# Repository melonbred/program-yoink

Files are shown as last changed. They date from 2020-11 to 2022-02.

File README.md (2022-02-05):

# Program Yoink!

This PCB is for a 12u main cluster with exploded arrow cluster, macro column and rotary encoder support. Progam Yoink! was a collaborative project with Steve Laroo, P3D Store, and Keybage. 

- Big bar and split bar support
- MX switch support only
- USB Type-C.
- ESD Protection
- RGB lightbar

## Layout
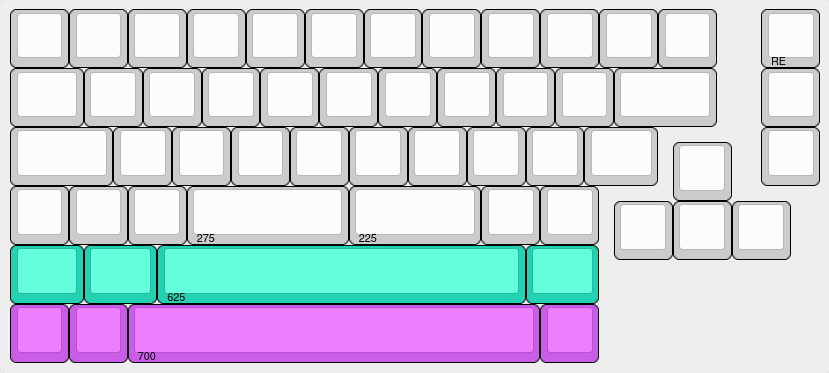
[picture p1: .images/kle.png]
 

[KLE](http://www.keyboard-layout-editor.com/#/gists/345cd9f384dae3f91f5151f02f8af4df)

 ## PCB
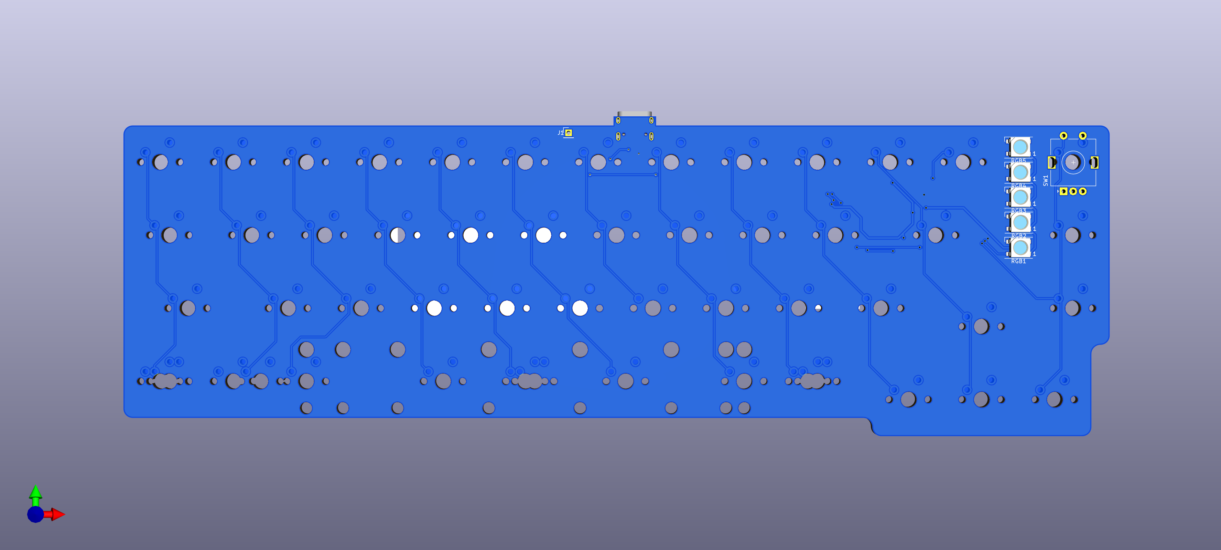
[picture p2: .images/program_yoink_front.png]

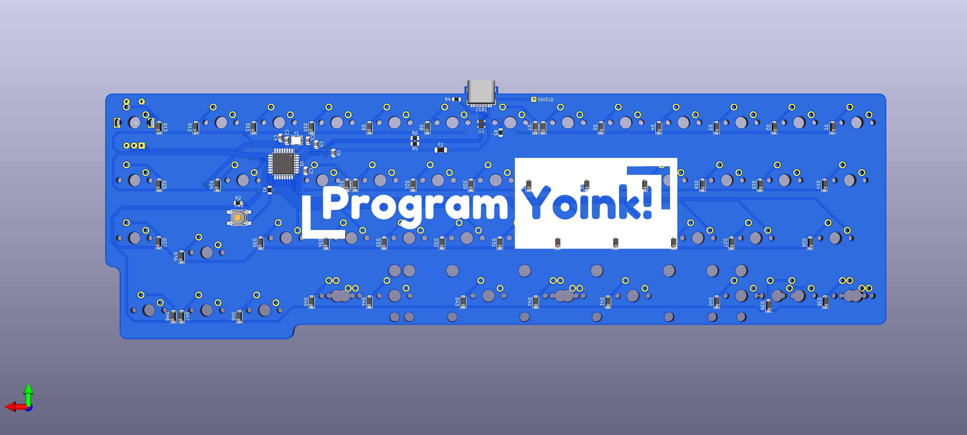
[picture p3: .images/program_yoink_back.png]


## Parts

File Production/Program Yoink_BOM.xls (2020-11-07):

Item No. | Designator | Quantity | Value | Footprint | Manufacturer | Part No. | Description
1 | R2,R1 | 2 | 10k | 0805 | Panasonic Electronic Components | ERA-6AEB103V | RES 10K OHM 0.1% 1/8W 0805
2 | USB1 | 1 | HRO-TYPE-C-31-M-12 | HRO-TYPE-C-31-M-12-HandSoldering | Korean Hroparts Elec | TYPE-C-31-M-12 | USB - Type C Female 16 8.94*7.3mm USB Connectors RoHS
3 | U2 | 1 | PRTR5V0U2X | SOT-143 | Nexperia USA Inc. | PRTR5V0U2X,215 | TVS DIODE 5.5V SOT143B
4 | R4,R3 | 2 | 5.1k | 0805 | Panasonic Electronic Components | ERA-6AEB512V | 5.1 ±0.1% 0.125W, 1/8W Chip Resistor 0805 (2012 Metric) Automotive AEC-Q200 Thin Film
5 | F1 | 1 | Polyfuse_Small | 1206 | Bel Fuse Inc. | 0ZCJ0050AF2E | PTC RESET FUSE 24V 500MA 1206
6 | R5, R6 | 2 | 22 | 0805 | Panasonic Electronic Components | ERJ-6BWJR022V | RES 0.022 OHM 5% 1/2W 0805
7 | Y1 | 1 | Crystal_GND24_Small | 3225 | Kyocera International Inc. Electronic Components | CX3225SB16000D0GZJC1 | CRYSTAL 16.0000MHZ 8PF SMD
8 | SW2 | 1 | SW_Push |  | CKN10361CT-ND | RS-187R05A2-DS MT RT | SWITCH TACTILE SPST-NO 0.05A 12V
9 | C6 | 1 | 10uF | 0805 | Samsung Electro-Mechanics | CL21A106KOQNNNG | CAP CER 10UF 16V X5R 0805
10 | C5,C4 | 2 | 0.1uF | 0805 | Samsung Electro-Mechanics | CL21B104MBCNNNC | CAP CER 0.1UF 50V X7R 0805
11 | C3 | 1 | 1uF | 0805 | Samsung Electro-Mechanics | CL21B105KAFNNNE | CAP CER 1UF 25V X7R 0805
12 | C2,C1 | 2 | 22pF | 0805 | Samsung Electro-Mechanics | CL21C220JB61PNC | CAP CER 22PF 50V C0G/NP0 0805
13 | U1 | 1 | ATmega32U2-AU | TQFP-32_7x7mm_P0.8mm | Microchip Technology | ATMEGA32U2-AU | IC MCU 8BIT 32KB FLASH 32TQFP
14 | D46,D48,D47,D45,D44,D43,D42,D41,D40,D39,D38,D37,D36,D35,D34,D33,D32,D31,D30,D29,D28,D27,D26,D25,D24,D23,D22,D21,D20,D19,D18,D17,D16,D15,D14,D13,D12,D11,D10,D9,D8,D7,D6,D5,D4,D3,D2,D1 | 48 | 1N4148 | SOD-123 | Micro Commercial Co | 1N4148W-TP | DIODE GEN PURP 100V 150MA SOD123
15 | RGB1, RGB2, RGB3, RGB4, RGB5 | 5 | WS2812B-B | SMD,5x5mm | Worldsemi | WS2812B-B | RGB 620~630nmRed,515~530nmGreen,465~475nmBlue SMD,5x5mm Light Emitting Diodes (LED) RoHS

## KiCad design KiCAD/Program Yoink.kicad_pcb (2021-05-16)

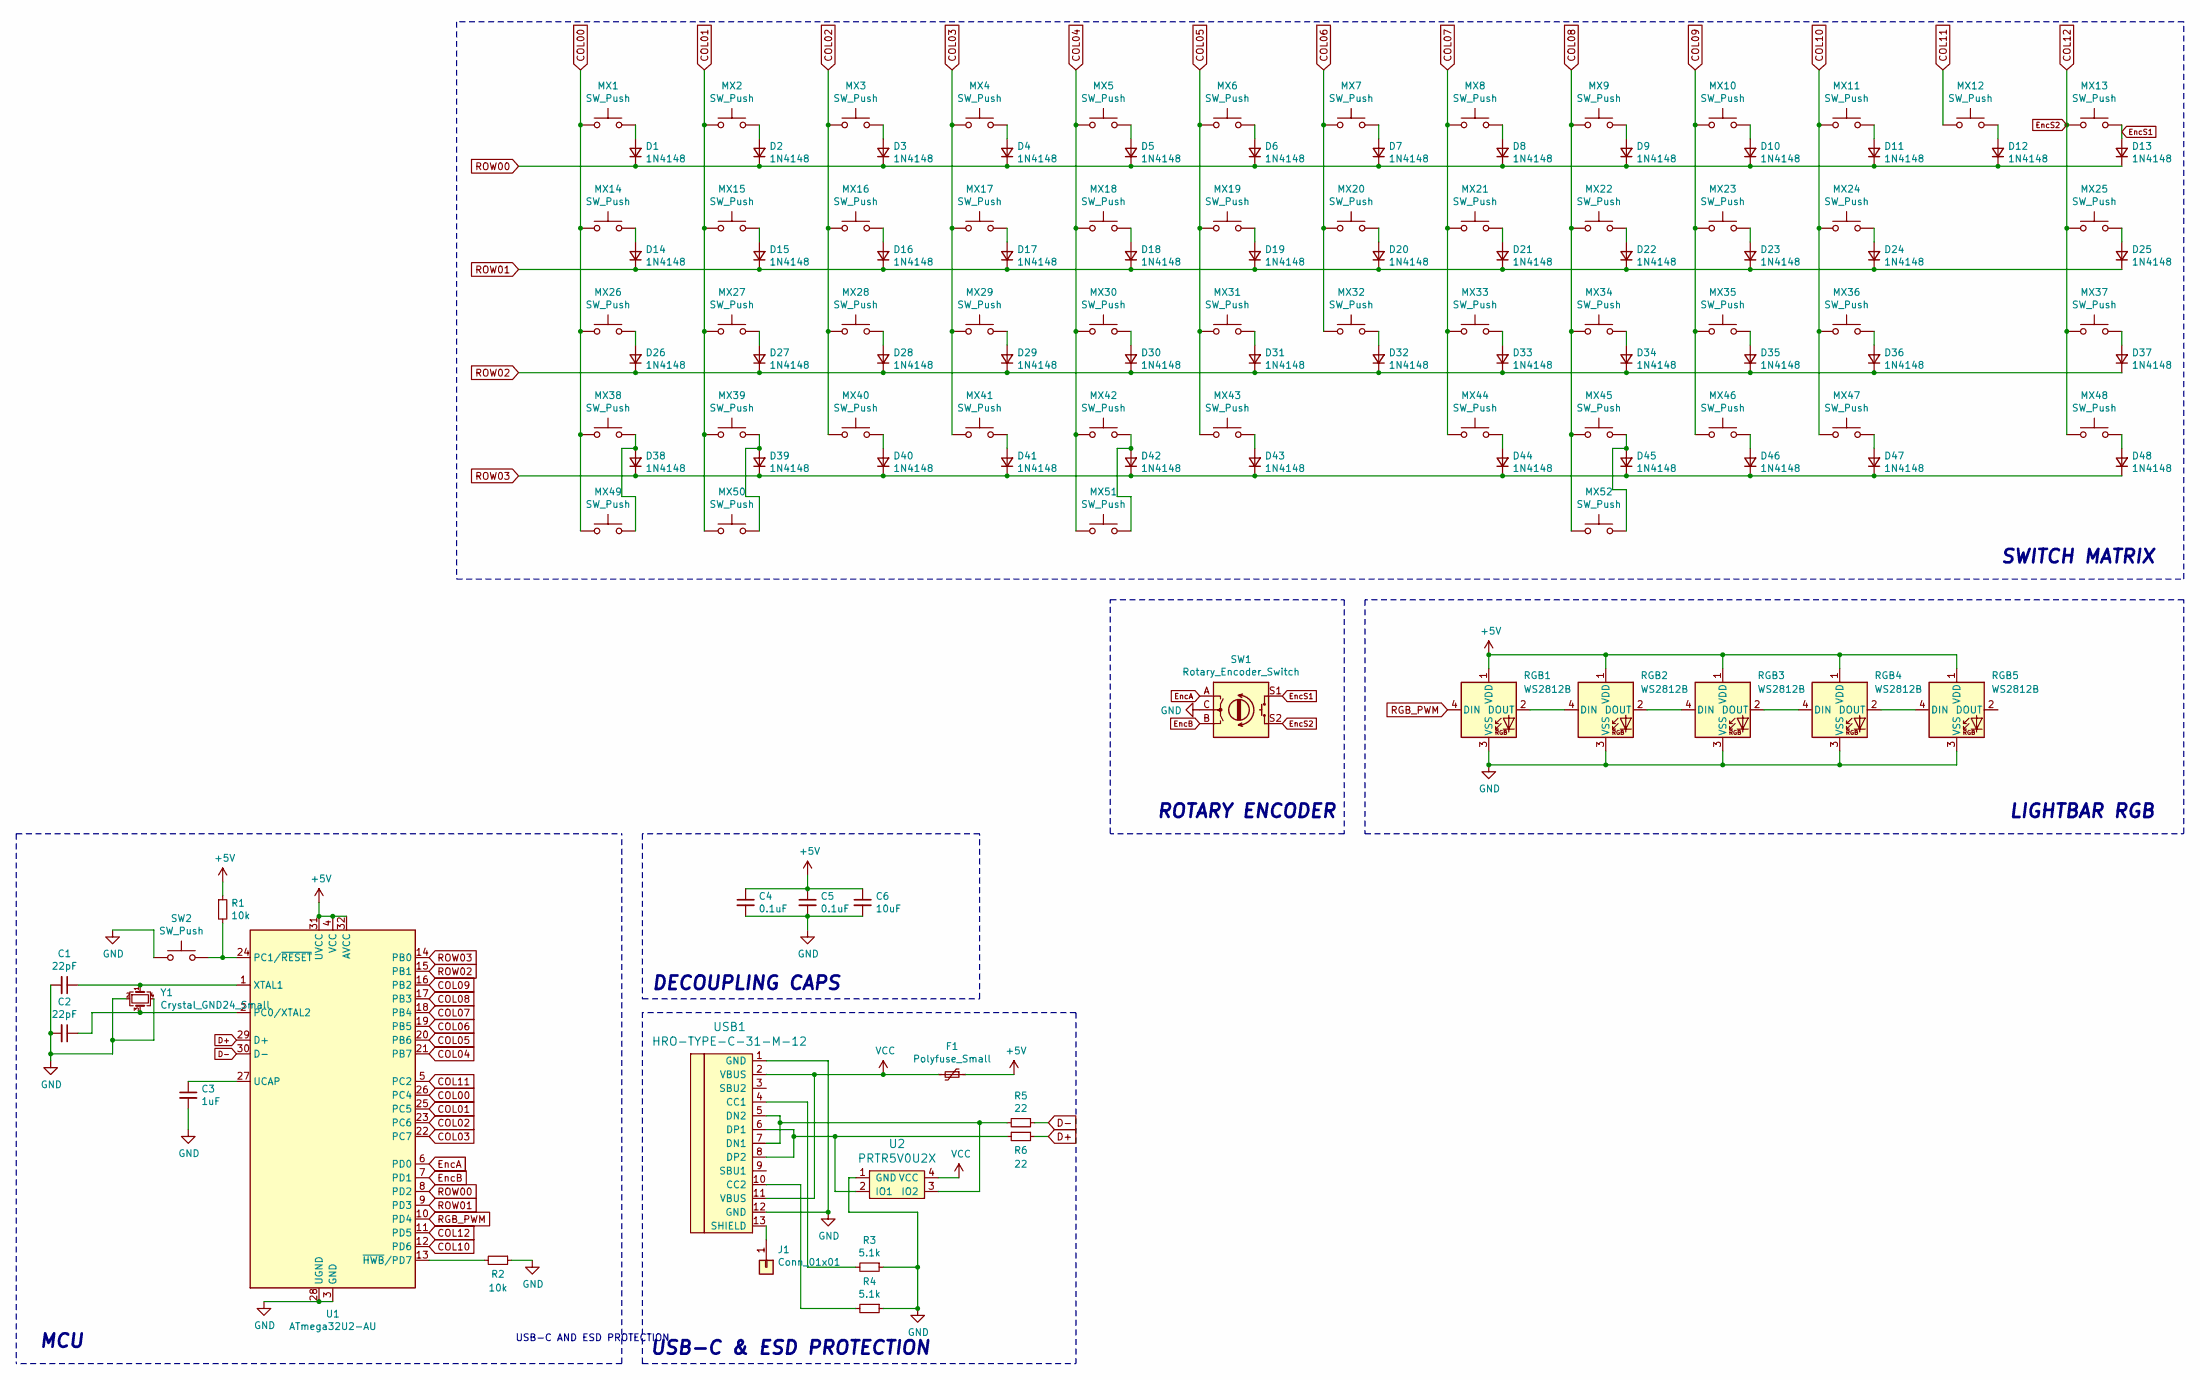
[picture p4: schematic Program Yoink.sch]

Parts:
C1, C2: 22pF; C_0805_2012Metric
C3: 1uF; C_0805_2012Metric
C4, C5: 0.1uF; C_0805_2012Metric
C6: 10uF; C_0805_2012Metric
D1, D2, D3, D4, D5, D6, D7, D8, D9, D10, D11, D12, D13, D14, D15, D16, D17, D18, D19, D20, D21, D22, D23, D24, D25, D26, D27, D28, D29, D30, D31, D32, D33, D34, D35, D36, D37, D38, D39, D40, D41, D42, D43, D44, D45, D46, D47, D48: 1N4148; D_SOD-123
F1: Polyfuse_Small; Fuse_1206_3216Metric
J1: Conn_01x01
MX1, MX2, MX3, MX4, MX5, MX6, MX7, MX8, MX9, MX10, MX11, MX12, MX13, MX15, MX16, MX17, MX18, MX19, MX20, MX21, MX22, MX23, MX25, MX27, MX28, MX29, MX30, MX31, MX32, MX33, MX34, MX36, MX37, MX38, MX39, MX40, MX44, MX45, MX46, MX47, MX48: SW_Push; MXOnly-1U-NoLED
MX14, MX35, MX49, MX50, MX52: SW_Push; MXOnly-1.25U-NoLED
MX24, MX26: SW_Push; MXOnly-1.75U-NoLED
MX41: SW_Push; MXOnly-2.75U-ReversedStabilizers-NoLED
MX42: SW_Push; MXOnly-7U-ReversedStabilizers-NoLED
MX43: SW_Push; MXOnly-2.25U-ReversedStabilizers-NoLED
MX51: SW_Push; MXOnly-6.25U-ReversedStabilizers-NoLED
R1, R2: 10k; R_0805_2012Metric
R3, R4: 5.1k; R_0805_2012Metric
R5, R6: 22; R_0805_2012Metric
RGB1, RGB2, RGB3, RGB4, RGB5: WS2812B; LED_WS2812B_PLCC4_5.0x5.0mm_P3.2mm
SW1: Rotary_Encoder_Switch; RotaryEncoder_Alps_EC11E-Switch_Vertical_H20mm
SW2: SW_Push; SKQGADE010
U1: ATmega32U2-AU; TQFP-32_7x7mm_P0.8mm
U2: PRTR5V0U2X; SOT143B
USB1: HRO-TYPE-C-31-M-12; HRO-TYPE-C-31-M-12-Assembly
Y1: Crystal_GND24_Small; Crystal_SMD_3225-4Pin_3.2x2.5mm

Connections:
+5V: C4.1, C5.1, C6.1, F1.1, R1.1, RGB1.1 (VDD), RGB2.1 (VDD), RGB3.1 (VDD), RGB4.1 (VDD), RGB5.1 (VDD), U1.4 (VCC), U1.31 (UVCC), U1.32 (AVCC)
COL00: MX1.1, MX14.1, MX26.1, MX38.1, MX49.1, U1.26 (PC4)
COL01: MX2.1, MX15.1, MX27.1, MX39.1, MX50.1, U1.25 (PC5)
COL02: MX3.1, MX16.1, MX28.1, MX40.1, U1.23 (PC6)
COL03: MX4.1, MX17.1, MX29.1, MX41.1, U1.22 (PC7)
COL04: MX5.1, MX18.1, MX30.1, MX42.1, MX51.1, U1.21 (PB7)
COL05: MX6.1, MX19.1, MX31.1, MX43.1, U1.20 (PB6)
COL06: MX7.1, MX20.1, MX32.1, U1.19 (PB5)
COL07: MX8.1, MX21.1, MX33.1, MX44.1, U1.18 (PB4)
COL08: MX9.1, MX22.1, MX34.1, MX45.1, MX52.1, U1.17 (PB3)
COL09: MX10.1, MX23.1, MX35.1, MX46.1, U1.16 (PB2)
COL10: MX11.1, MX24.1, MX36.1, MX47.1, U1.12 (PD6)
COL11: MX12.1, U1.5 (PC2)
COL12: MX13.1, MX25.1, MX37.1, MX48.1, SW1.S2, U1.11 (PD5)
D+: R6.1, U1.29 (D+)
D-: R5.1, U1.30 (D-)
EncA: SW1.A, U1.6 (PD0)
EncB: SW1.B, U1.7 (PD1)
EncS1: D13.2 (A), MX13.2, SW1.S1
GND: C1.2, C2.2, C3.2, C4.2, C5.2, C6.2, R2.1, R3.1, R4.1, RGB1.3 (VSS), RGB2.3 (VSS), RGB3.3 (VSS), RGB4.3 (VSS), RGB5.3 (VSS), SW1.C, SW2.1, U1.3 (GND), U1.28 (UGND), U2.1 (GND), USB1.1 (GND), USB1.12 (GND), Y1.2, Y1.4
unnamed: C1.1, U1.1 (XTAL1), Y1.1
unnamed: C2.1, U1.2 (PC0/XTAL2), Y1.3
unnamed: C3.1, U1.27 (UCAP)
unnamed: D1.2 (A), MX1.2
unnamed: D2.2 (A), MX2.2
unnamed: D3.2 (A), MX3.2
unnamed: D4.2 (A), MX4.2
unnamed: D5.2 (A), MX5.2
unnamed: D6.2 (A), MX6.2
unnamed: D7.2 (A), MX7.2
unnamed: D8.2 (A), MX8.2
unnamed: D9.2 (A), MX9.2
unnamed: D10.2 (A), MX10.2
unnamed: D11.2 (A), MX11.2
unnamed: D12.2 (A), MX12.2
unnamed: D14.2 (A), MX14.2
unnamed: D15.2 (A), MX15.2
unnamed: D16.2 (A), MX16.2
unnamed: D17.2 (A), MX17.2
unnamed: D18.2 (A), MX18.2
unnamed: D19.2 (A), MX19.2
unnamed: D20.2 (A), MX20.2
unnamed: D21.2 (A), MX21.2
unnamed: D22.2 (A), MX22.2
unnamed: D23.2 (A), MX23.2
unnamed: D24.2 (A), MX24.2
unnamed: D25.2 (A), MX25.2
unnamed: D26.2 (A), MX26.2
unnamed: D27.2 (A), MX27.2
unnamed: D28.2 (A), MX28.2
unnamed: D29.2 (A), MX29.2
unnamed: D30.2 (A), MX30.2
unnamed: D31.2 (A), MX31.2
unnamed: D32.2 (A), MX32.2
unnamed: D33.2 (A), MX33.2
unnamed: D34.2 (A), MX34.2
unnamed: D35.2 (A), MX35.2
unnamed: D36.2 (A), MX36.2
unnamed: D37.2 (A), MX37.2
unnamed: D38.2 (A), MX38.2, MX49.2
unnamed: D39.2 (A), MX39.2, MX50.2
unnamed: D40.2 (A), MX40.2
unnamed: D41.2 (A), MX41.2
unnamed: D42.2 (A), MX42.2, MX51.2
unnamed: D43.2 (A), MX43.2
unnamed: D44.2 (A), MX44.2
unnamed: D45.2 (A), MX45.2, MX52.2
unnamed: D46.2 (A), MX46.2
unnamed: D47.2 (A), MX47.2
unnamed: D48.2 (A), MX48.2
unnamed: J1.1, USB1.13 (SHIELD)
unnamed: R1.2, SW2.2, U1.24 (PC1/~RESET)
unnamed: R2.2, U1.13 (~HWB~/PD7)
unnamed: R3.2, USB1.4 (CC1)
unnamed: R4.2, USB1.10 (CC2)
unnamed: R5.2, U2.3 (IO2), USB1.5 (DN2), USB1.7 (DN1)
unnamed: R6.2, U2.2 (IO1), USB1.6 (DP1), USB1.8 (DP2)
unnamed: RGB1.2 (DOUT), RGB2.4 (DIN)
unnamed: RGB2.2 (DOUT), RGB3.4 (DIN)
unnamed: RGB3.2 (DOUT), RGB4.4 (DIN)
unnamed: RGB4.2 (DOUT), RGB5.4 (DIN)
RGB_PWM: RGB1.4 (DIN), U1.10 (PD4)
ROW00: D1.1 (K), D2.1 (K), D3.1 (K), D4.1 (K), D5.1 (K), D6.1 (K), D7.1 (K), D8.1 (K), D9.1 (K), D10.1 (K), D11.1 (K), D12.1 (K), D13.1 (K), U1.8 (PD2)
ROW01: D14.1 (K), D15.1 (K), D16.1 (K), D17.1 (K), D18.1 (K), D19.1 (K), D20.1 (K), D21.1 (K), D22.1 (K), D23.1 (K), D24.1 (K), D25.1 (K), U1.9 (PD3)
ROW02: D26.1 (K), D27.1 (K), D28.1 (K), D29.1 (K), D30.1 (K), D31.1 (K), D32.1 (K), D33.1 (K), D34.1 (K), D35.1 (K), D36.1 (K), D37.1 (K), U1.15 (PB1)
ROW03: D38.1 (K), D39.1 (K), D40.1 (K), D41.1 (K), D42.1 (K), D43.1 (K), D44.1 (K), D45.1 (K), D46.1 (K), D47.1 (K), D48.1 (K), U1.14 (PB0)
VCC: F1.2, U2.4 (VCC), USB1.2 (VBUS), USB1.11 (VBUS)

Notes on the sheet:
SWITCH MATRIX
LIGHTBAR RGB
MCU
DECOUPLING CAPS
USB-C AND ESD PROTECTION
USB-C & ESD PROTECTION
ROTARY ENCODER

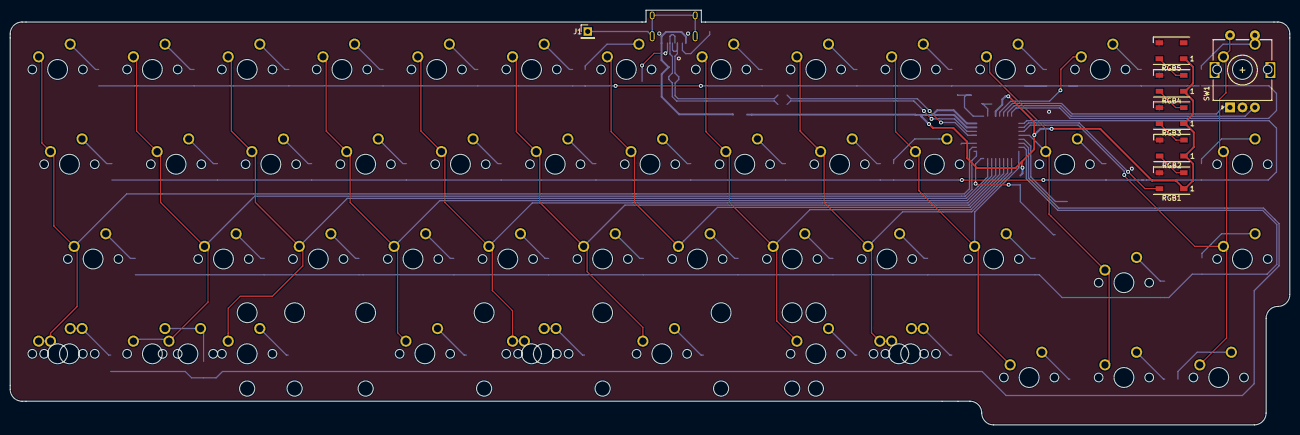
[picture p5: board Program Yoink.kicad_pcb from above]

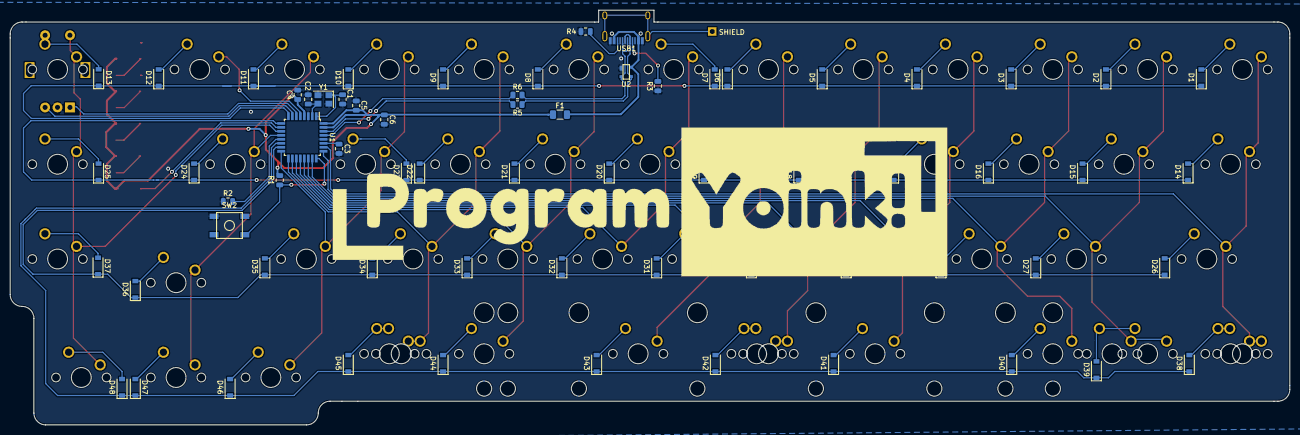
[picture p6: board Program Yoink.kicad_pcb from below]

Board: 2 copper layers, 257.2 x 83.3 mm, 125 parts (66 on the bottom side), 87 nets.

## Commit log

2020-10-03 Completed v0.1 PCB
    [Program Yoink.kicad_pcb, Program Yoink.sch]
2020-10-03 Updated Symbol lib path
    [Program Yoink.kicad_pcb, Program Yoink.sch]
2020-10-16 Fixed LED gnd
    [Program Yoink-B_Cu.gbl, Program Yoink-B_Mask.gbs, Program Yoink-B_Paste.gbp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]
2020-10-24 Updated traces
    [Program Yoink.kicad_pcb, Program Yoink.sch]
2020-11-04 Updated PCB
    Added resistors to data lines
    [Program Yoink.kicad_pcb, Program Yoink.sch]
2020-11-06 Added data resistors
    [Program Yoink.kicad_pcb]
2020-11-07 Prepared production files
    [Program Yoink-B_Cu.gbl, Program Yoink-B_Mask.gbs, Program Yoink-B_Paste.gbp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]
2020-12-04 Updated PCB
    [Program Yoink-B_Cu.gbl, Program Yoink-B_Mask.gbs, Program Yoink-B_SilkS.gbo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]
2021-05-16 Production Files
    [Program Yoink.kicad_pcb, Program Yoink_BOM.xls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]
2021-05-16 Added images
    [Program Yoink.kicad_pcb]
